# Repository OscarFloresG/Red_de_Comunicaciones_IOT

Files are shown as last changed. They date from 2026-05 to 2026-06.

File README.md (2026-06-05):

# Red de Comunicaciones IoT para - UABC

Este repositorio contiene el ecosistema de desarrollo de hardware y firmware para la implementación de una red privada de telemetría inalámbrica de largo alcance y bajo consumo, diseñada en vinculación con el Instituto de Ingeniería de la Universidad Autónoma de Baja California (UABC) para el monitoreo de consumo eléctrico en comunidades aisladas (Caso de estudio: Puertecitos, B.C.).

El sistema implementa la tecnología de radiofrecuencia LoRa en la banda libre de 915 MHz, logrando una tasa de pérdida de paquetes muy baja en entornos exteriores a distancias críticas de 300 metros, superando la atenuación por obstáculos físicos y mitigando colisiones por transmisiones concurrentes.

---

## 🛠️ Estructura del Repositorio

* `/placa_lora2`: Archivos de diseño asistido por computadora (CAD) electrónicos correspondientes a la primera etapa de la PCB adaptadora para la integración del transceptor RFM95W y el microcontrolador.
* `/PVVCSMD`: Proyecciones y diseños avanzados de la placa de circuito impreso migrada a tecnología de montaje superficial (SMD) para la optimización de espacio y reducción de costos de fabricación.
* `emisorLora.ino`: Código fuente en C++ para los nodos emisores integrados en los medidores comunitarios. Implementa la estructura de la trama personalizada y el algoritmo de desfasamiento temporal.
* `receptorCentralLora.ino`: Código fuente en C++ para el nodo base centralizador o Gateway encargado de la recepción simultánea, validación de redundancia de errores y puenteo de datos hacia servidores en la nube.

---

## 💻 Descripción de los Códigos de Firmware

### 1. Emisor (`emisorLora.ino`)
Firmware programado para ejecutarse en las unidades remotas de medición. Sus funciones principales son:
* **Estructuración de Trama Propia:** Empaqueta los datos de telemetría bajo un formato optimizado de bajo overhead: `[ID | Seq | Len | Payload | Checksum]` para agilizar el tiempo en el aire (Time-on-Air).
* **Algoritmo de Jitter Aleatorio (Anticolisiones):** Utiliza el ruido electromagnético caótico captado por un pin analógico configurado al aire como semilla para generar un desfasamiento dinámico de +/- 800 ms. Esto evita que los nodos que transmiten simultáneamente bloqueen el canal de comunicación.
* **Control de Errores:** Realiza cálculos de redundancia de datos mediante suma de verificación XOR por software antes de enviar el paquete por el transceptor.

### 2. Receptor Central (`receptorCentralLora.ino`)
Firmware dedicado al Gateway o nodo base de recolección local. Sus funciones principales son:
* **Escucha Concurrente y Modulación:** Configura el módulo de radio bajo parámetros de alta sensibilidad en la frecuencia de 915 MHz, Ancho de Banda (BW) de 125 kHz y Factor de Ensanchamiento (SF) de 7.
* **Doble Validación de Integridad:** Corrobora la exactitud de los bits recibidos mediante el análisis combinado de CRC por hardware y la verificación XOR por software, descartando tramas corruptas provocadas por interferencias del entorno.
* **Métricas de Diagnóstico:** Extrae y evalúa en tiempo real los valores de RSSI (Indicador de Fuerza de Señal Recibida) y SNR (Relación Señal-Ruido) para el diagnóstico físico del enlace.

---

## 📡 Especificaciones de Radiofrecuencia (RF)
* **Tecnología:** LoRa (Chipset Semtech SX1276 / RFM95W)
* **Frecuencia:** 915 MHz (Banda ISM libre para México)
* **Ancho de Banda (BW):** 125 kHz
* **Spreading Factor (SF):** 7
* **Potencia de Salida:** 17 dBm (50 mW)

---

## 👥 Desarrolladores
* Diego Castañeda Covarrubias
* Oscar Eduardo Flores García
* Herick Gerardo Vizcarra Macías

*Proyecto de Vinculación con Valor en Créditos (PVVC) bajo la mentoría del Dr. Saúl - Laboratorio de Energías Renovables, Instituto de Ingeniería de la UABC.*

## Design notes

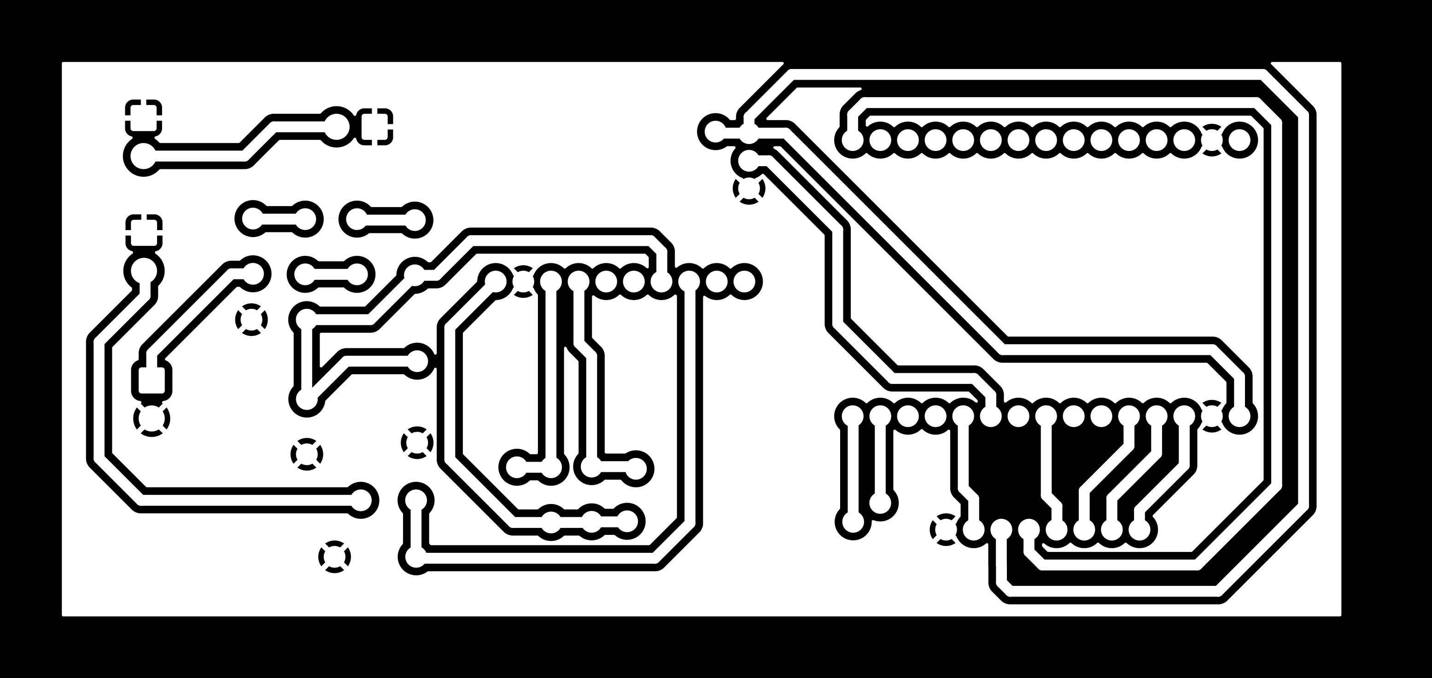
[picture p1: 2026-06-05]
placa_ceener/placa_ceener/placa_ceener-B_Cu.png

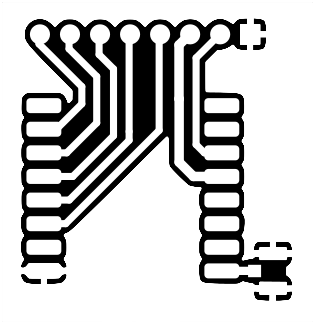
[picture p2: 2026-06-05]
placa_lora2/placa_lora2/placa_lora2-F_Cu.png

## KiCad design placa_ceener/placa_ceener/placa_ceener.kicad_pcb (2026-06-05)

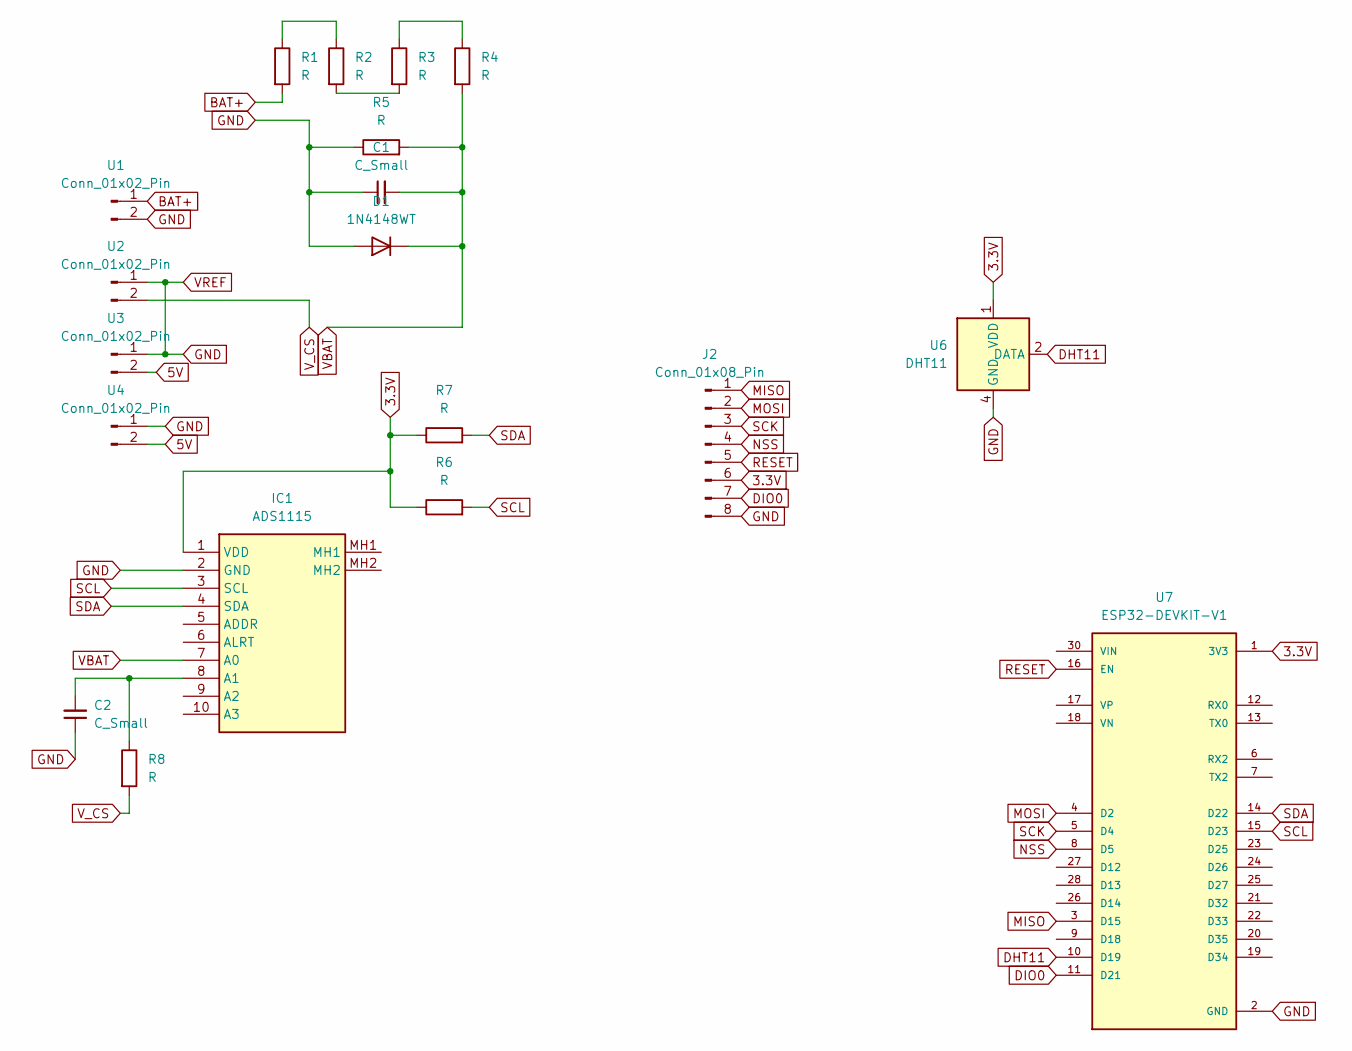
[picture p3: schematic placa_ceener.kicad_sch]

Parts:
C1, C2: C_Small; C_Axial_L3.8mm_D2.6mm_P7.50mm_Horizontal
D1: 1N4148WT; D_DO-34_SOD68_P5.08mm_Vertical_KathodeUp
IC1: ADS1115; Manufacturer_Part_Number ADS1115
J2: Conn_01x08_Pin; PinHeader_1x08_P2.54mm_Vertical
R1, R2, R3, R4, R5, R6, R7, R8: R; R_Axial_DIN0204_L3.6mm_D1.6mm_P5.08mm_Horizontal
U1, U2, U3, U4: Conn_01x02_Pin; TerminalBlock_4Ucon_1x02_P3.50mm_Horizontal
U6: DHT11; Aosong_DHT11_5.5x12.0_P2.54mm
U7: ESP32-DEVKIT-V1; MODULE_ESP32_DEVKIT_V1; PARTREV N/A

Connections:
3.3V: IC1.1 (VDD), J2.6, R6.1, R7.1, U6.1 (VDD), U7.1 (3V3)
5V: U3.2, U4.2
BAT+: R1.2, U1.1
DHT11: U6.2 (DATA), U7.10 (D19)
DIO0: J2.7, U7.11 (D21)
GND: C1.1, C2.1, D1.2 (A), IC1.2 (GND), J2.8, R5.1, U1.2, U2.1, U3.1, U4.1, U6.4 (GND), U7.2 (GND), U7.29 (GND)
MISO: J2.1, U7.3 (D15)
MOSI: J2.2, U7.4 (D2)
NSS: J2.4, U7.8 (D5)
unnamed: C2.2, IC1.8 (A1), R8.1
unnamed: R1.1, R2.1
unnamed: R2.2, R3.2
unnamed: R3.1, R4.1
RESET: J2.5, U7.16 (EN)
SCK: J2.3, U7.5 (D4)
SCL: IC1.3 (SCL), R6.2, U7.15 (D23)
SDA: IC1.4 (SDA), R7.2, U7.14 (D22)
VBAT: C1.2, D1.1 (K), IC1.7 (A0), R4.2, R5.2
V_CS: R8.2, U2.2

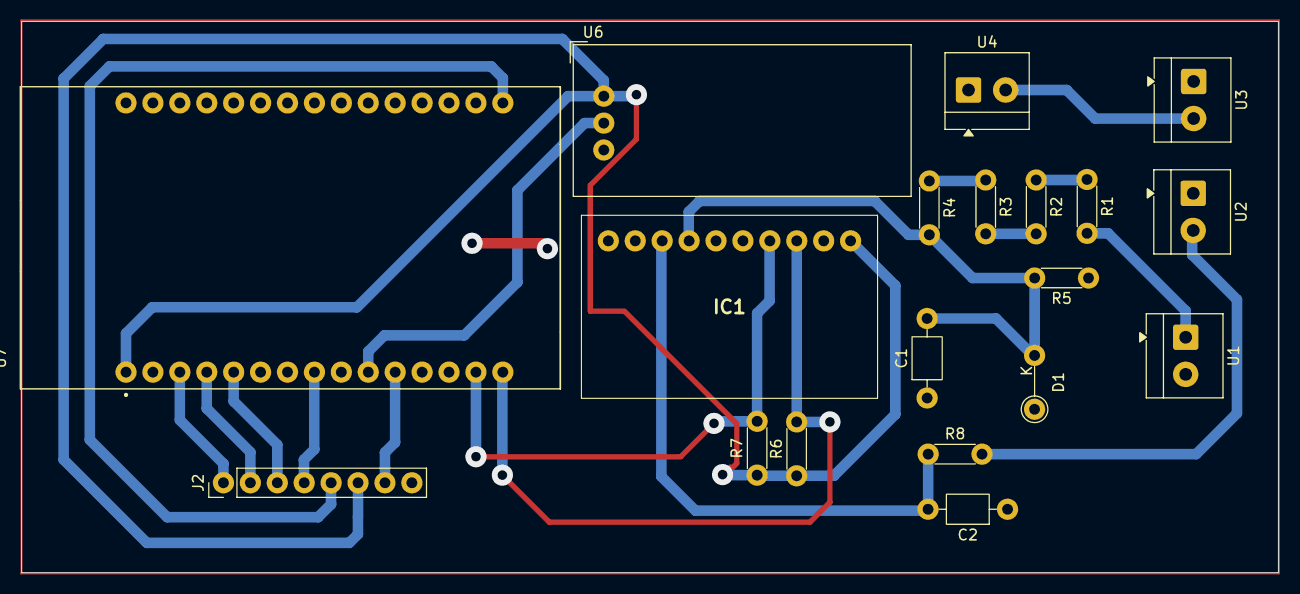
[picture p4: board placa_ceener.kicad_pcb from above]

Board: 2 copper layers, 118.6 x 52.0 mm, 19 parts (0 on the bottom side), 19 nets.

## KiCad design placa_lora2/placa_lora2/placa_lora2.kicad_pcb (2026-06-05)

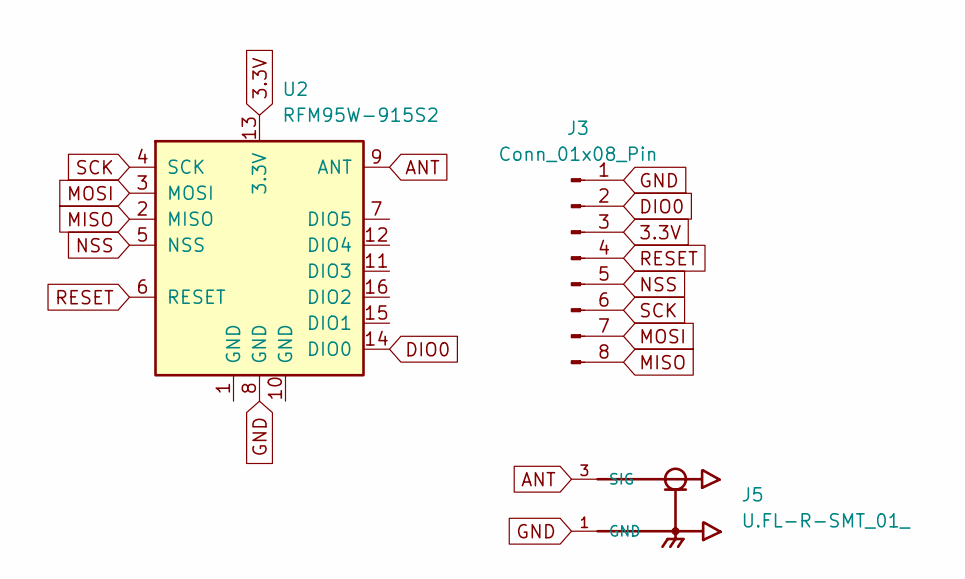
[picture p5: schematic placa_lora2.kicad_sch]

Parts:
J3: Conn_01x08_Pin; PinHeader_1x08_P2.54mm_Vertical
J5: U.FL-R-SMT_01_; HRS_U.FL-R-SMT_01_
U2: RFM95W-915S2; HOPERF_RFM9XW_SMD

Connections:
3.3V: J3.3, U2.13 (3.3V)
ANT: J5.3 (SIG), U2.9 (ANT)
DIO0: J3.2, U2.14 (DIO0)
GND: J3.1, J5.1 (GND), J5.2 (GND), U2.8 (GND)
MISO: J3.8, U2.2 (MISO)
MOSI: J3.7, U2.3 (MOSI)
NSS: J3.5, U2.5 (NSS)
RESET: J3.4, U2.6 (RESET)
SCK: J3.6, U2.4 (SCK)

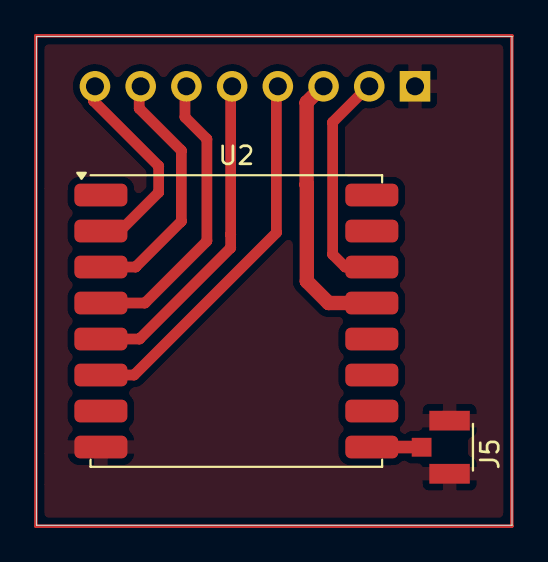
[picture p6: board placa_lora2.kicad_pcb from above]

Board: 2 copper layers, 26.4 x 27.2 mm, 3 parts (1 on the bottom side), 9 nets.

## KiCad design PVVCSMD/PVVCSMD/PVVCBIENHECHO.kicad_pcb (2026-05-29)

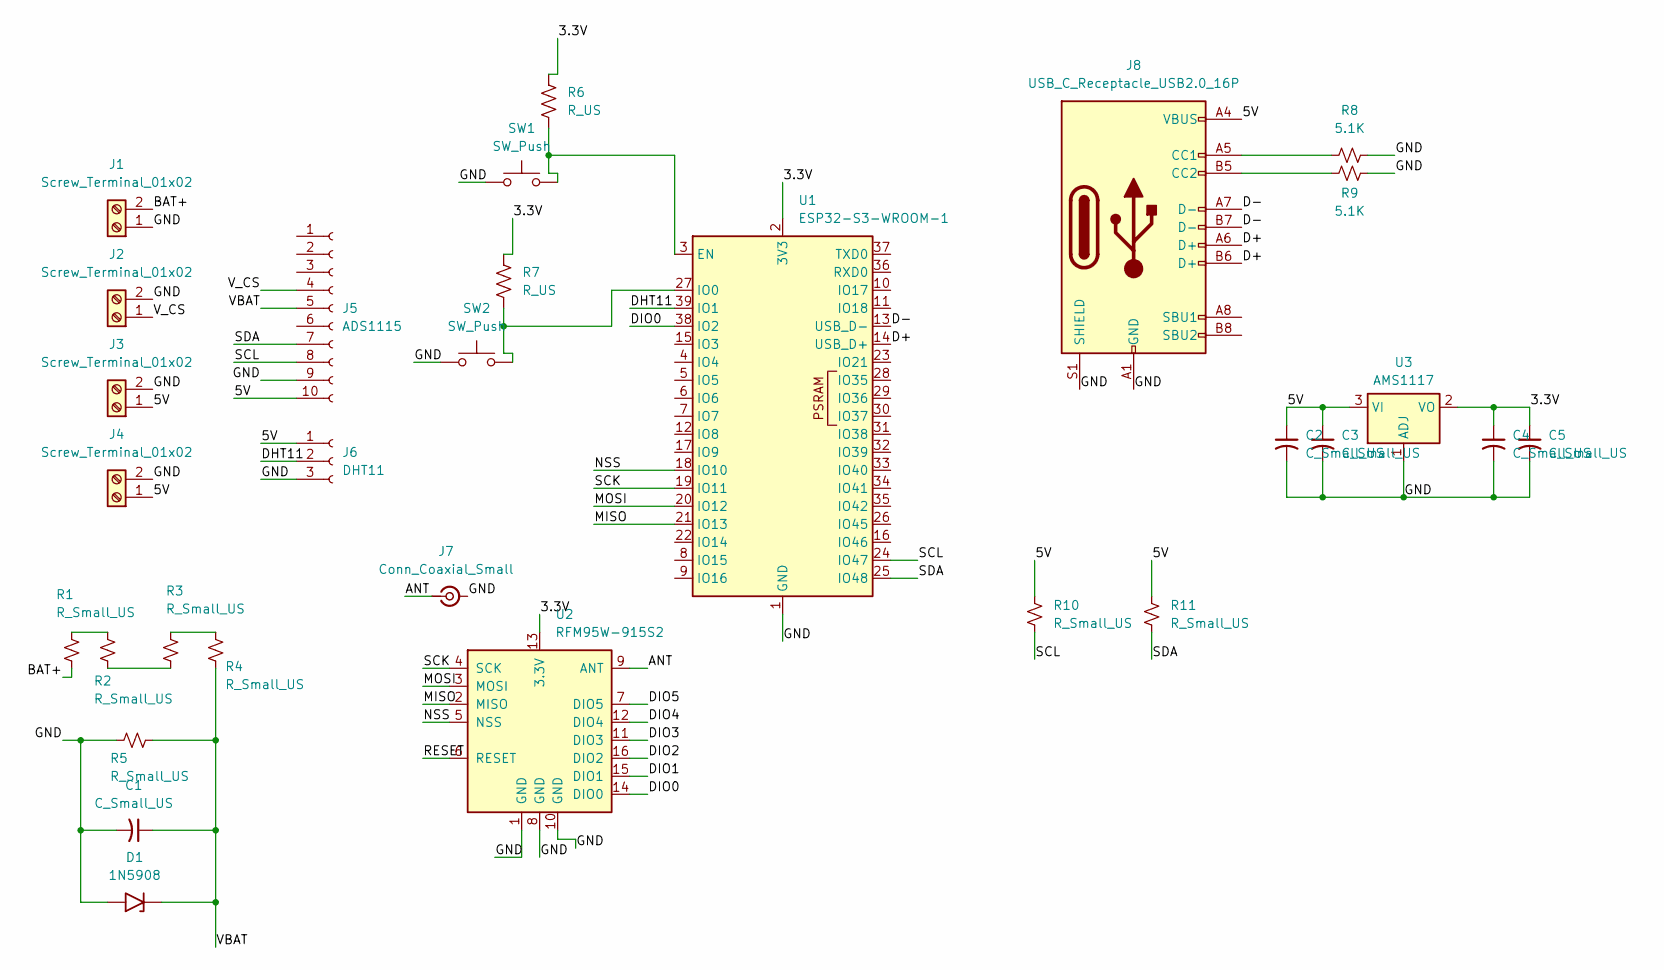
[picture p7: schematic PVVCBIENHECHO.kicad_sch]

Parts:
C1, C2, C3, C4, C5: C_Small_US; C_1206_3216Metric
D1: 1N5908; D_1206_3216Metric
J1, J2, J3, J4: Screw_Terminal_01x02; TerminalBlock_Xinya_XY308-2.54-2P_1x02_P2.54mm_Horizontal
J5: ADS1115; PinSocket_1x10_P2.54mm_Vertical
J6: DHT11; PinSocket_1x03_P2.54mm_Vertical
J7: Conn_Coaxial_Small; U.FL_Hirose_U.FL-R-SMT-1_Vertical
J8: USB_C_Receptacle_USB2.0_16P; USB_C_Receptacle_HRO_TYPE-C-31-M-12
R1, R2, R3, R4, R5, R10, R11: R_Small_US; R_1206_3216Metric
R6, R7: R_US; R_1206_3216Metric
R8, R9: 5.1K; R_1206_3216Metric
SW1, SW2: SW_Push; SW_PUSH_6mm_H8mm
U1: ESP32-S3-WROOM-1
U2: RFM95W-915S2; HOPERF_RFM9XW_SMD
U3: AMS1117; SOT-223-3_TabPin2

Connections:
/3.3V: C4.1, C5.1, R6.1, R7.1, U1.2 (3V3), U2.13 (3.3V), U3.2 (VO)
/5V: C2.1, C3.1, J3.1, J4.1, J5.10, J6.1, J8.A4 (VBUS), J8.A9 (VBUS), J8.B4 (VBUS), J8.B9 (VBUS), R10.1, R11.1, U3.3 (VI)
/ANT: J7.1 (In), U2.9 (ANT)
/BAT+: J1.2, R1.2
/D+: J8.A6 (D+), J8.B6 (D+), U1.14 (USB_D+)
/D-: J8.A7 (D-), J8.B7 (D-), U1.13 (USB_D-)
/DHT11: J6.2, U1.39 (IO1)
/DIO0: U1.38 (IO2), U2.14 (DIO0)
/DIO1: U2.15 (DIO1)
/DIO2: U2.16 (DIO2)
/DIO3: U2.11 (DIO3)
/DIO4: U2.12 (DIO4)
/DIO5: U2.7 (DIO5)
/GND: C1.2, C2.2, C3.2, C4.2, C5.2, D1.2 (A2), J1.1, J2.2, J3.2, J4.2, J5.9, J6.3, J7.2 (Ext), J8.A1 (GND), J8.A12 (GND), J8.B1 (GND), J8.B12 (GND), J8.S1 (SHIELD), R5.2, R8.2, R9.2, SW1.1, SW2.1, U1.1 (GND), U1.40 (GND), U1.41 (GND), U2.1 (GND), U2.8 (GND), U2.10 (GND), U3.1 (ADJ)
/MISO: U1.21 (IO13), U2.2 (MISO)
/MOSI: U1.20 (IO12), U2.3 (MOSI)
/NSS: U1.18 (IO10), U2.5 (NSS)
/RESET: U2.6 (RESET)
/SCK: U1.19 (IO11), U2.4 (SCK)
/SCL: J5.8, R10.2, U1.24 (IO47)
/SDA: J5.7, R11.2, U1.25 (IO48)
/VBAT: C1.1, D1.1 (A1), J5.5, R4.2, R5.1
/V_CS: J2.1, J5.4
unnamed: J8.A5 (CC1), R8.1
unnamed: J8.B5 (CC2), R9.1
unnamed: R1.1, R2.1
unnamed: R2.2, R3.2
unnamed: R3.1, R4.1
unnamed: R6.2, SW1.2, U1.3 (EN)
unnamed: R7.2, SW2.2, U1.27 (IO0)

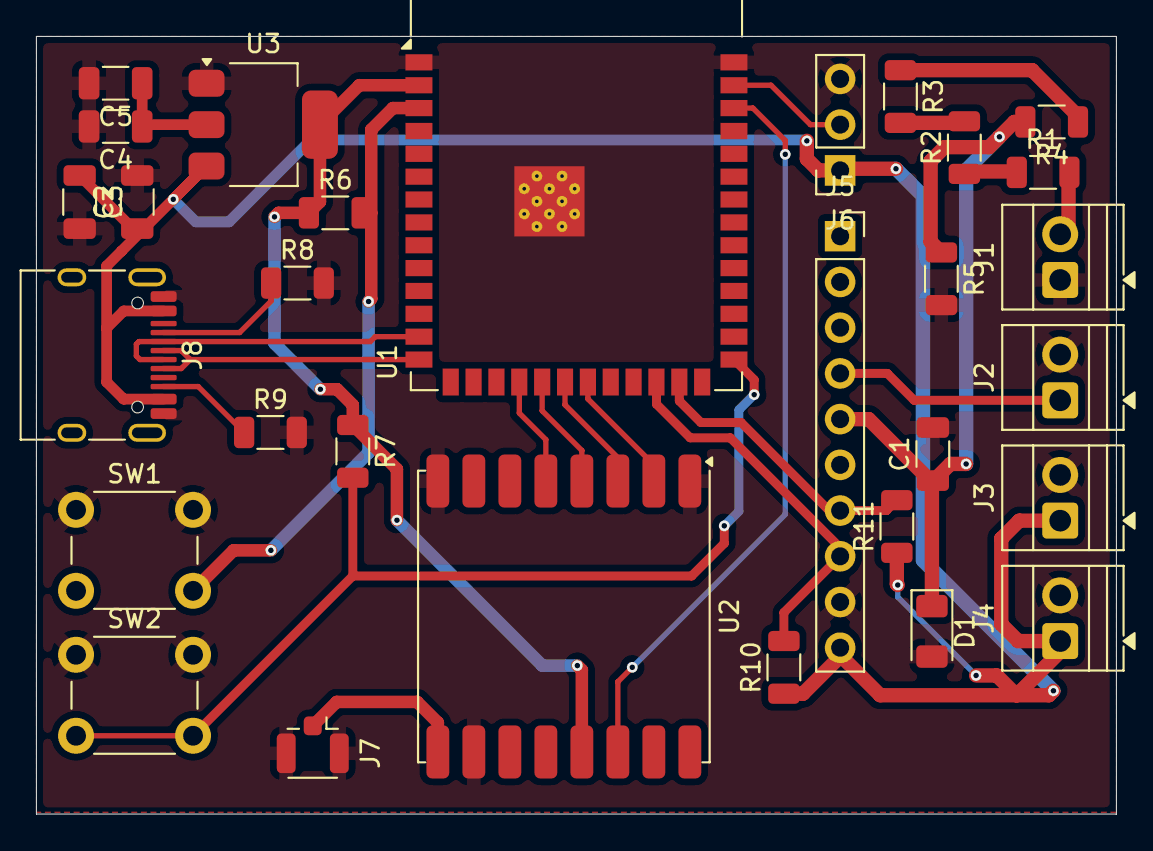
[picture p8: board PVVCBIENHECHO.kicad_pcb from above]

Board: 2 copper layers, 60.0 x 43.2 mm, 30 parts (0 on the bottom side), 24 nets.

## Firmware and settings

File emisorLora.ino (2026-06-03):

/*
 * =====================================================
 * NODO CLIENTE - LoRa Transmitter
 * ESP32 + LoRa SX1276/SX1278
 * =====================================================
 * *** ÚNICO CAMBIO ENTRE CLIENTES: NODE_ID (línea 30) ***
 * Cliente 1 → NODE_ID 0xA1
 * Cliente 2 → NODE_ID 0xA2
 * Cliente 3 → NODE_ID 0xA3
 * (y así sucesivamente...)
 *
 * Todos los demás parámetros deben ser IDÉNTICOS al base.
 * =====================================================
 */

#include <SPI.h>
#include <LoRa.h>

// ── Pines (TTGO LoRa32 / ajustar si es necesario) ──
#define LORA_SCK   4
#define LORA_MISO  15
#define LORA_MOSI  2
#define LORA_SS    5
#define LORA_RST   14
#define LORA_DIO0  21

// ── ★★ CAMBIA ESTO EN CADA ESP32 ★★ ──────────────
#define NODE_ID  0xA2          // 0xA1, 0xA2, 0xA3, 0xA4...
// ──────────────────────────────────────────────────

// ── Parámetros de radio (IDÉNTICOS en todos los nodos) ──
#define LORA_FREQ       915E6
#define LORA_BW         125E3
#define LORA_SF         9
#define LORA_CR         5
#define LORA_TX_POWER   17
#define LORA_PREAMBLE   8
#define LORA_SYNC_WORD  0xF3

// ── ID del nodo destino (base) ──
#define BASE_ID    0x00

// ── Intervalo base de transmisión (ms) y rango de Jitter ──
#define TX_INTERVAL_MS   5000    // Tiempo base: 5 segundos
#define JITTER_RANGE_MS  800     // Desfase de +/- 800ms (Total entre 4.2s y 5.8s)

// ── Estructura del paquete ──
#define PKT_SRC_ID      0
#define PKT_SEQ         1
#define PKT_LEN         2
#define PKT_PAYLOAD     3
#define PKT_HEADER_SIZE 3
#define PKT_MAX_PAYLOAD 50

// ── Contador de secuencia y tiempos ──
uint8_t seq_counter = 0;
uint32_t last_tx_ms = 0;
uint32_t current_interval = TX_INTERVAL_MS; // Intervalo dinámico actual

// ──────────────────────────────────────────────────
void setup() {
  Serial.begin(115200);
  delay(500);
  Serial.println("\n=== NODO CLIENTE LoRa ===");
  Serial.printf("  ID: 0x%02X  |  Destino: 0x%02X\n", NODE_ID, BASE_ID);

  // Inicializar semilla aleatoria usando ruido de un pin analógico sin conectar (ej. GPIO 34)
  // Esto evita que todos los emisores generen el mismo patrón al encenderse juntos.
  randomSeed(analogRead(34) + NODE_ID);

  SPI.begin(LORA_SCK, LORA_MISO, LORA_MOSI, LORA_SS);
  LoRa.setPins(LORA_SS, LORA_RST, LORA_DIO0);

  if (!LoRa.begin(LORA_FREQ)) {
    Serial.println("[ERROR] LoRa no inicializado. Revisa conexiones.");
    while (true) { delay(1000); }
  }

  LoRa.setSignalBandwidth(LORA_BW);
  LoRa.setSpreadingFactor(LORA_SF);
  LoRa.setCodingRate4(LORA_CR);
  LoRa.setTxPower(LORA_TX_POWER);
  LoRa.setPreambleLength(LORA_PREAMBLE);
  LoRa.setSyncWord(LORA_SYNC_WORD);
  LoRa.enableCrc();

  // Calcular el primer intervalo aleatorio para romper la simetría inicial
  current_interval = TX_INTERVAL_MS + random(-JITTER_RANGE_MS, JITTER_RANGE_MS);

  Serial.println("[OK] LoRa listo. Transmitiendo...\n");
}

// ──────────────────────────────────────────────────
void loop() {
  uint32_t now = millis();
  
  // Comparamos contra el intervalo dinámico en vez del estático
  if (now - last_tx_ms >= current_interval) {
    last_tx_ms = now;

    // Calcular el intervalo para el SIGUIENTE paquete
    current_interval = TX_INTERVAL_MS + random(-JITTER_RANGE_MS, JITTER_RANGE_MS);

    // ── Arma tu payload aquí ──────────────────────
    float temp   = 22.5 + (random(-30, 30) / 10.0);
    uint32_t uptime_s = now / 1000;

    char payload[PKT_MAX_PAYLOAD];
    int payload_len = snprintf(payload, sizeof(payload),
                               "T:%.1f C  up:%lus", temp, uptime_s);
    if (payload_len < 0 || payload_len >= PKT_MAX_PAYLOAD) {
      payload_len = PKT_MAX_PAYLOAD - 1;
    }
    // ─────────────────────────────────────────────

    send_packet((uint8_t*)payload, (uint8_t)payload_len);
    
    Serial.printf("[INFO] Próximo envío en: %.2f segundos.\n", current_interval / 1000.0);
  }
}

// ──────────────────────────────────────────────────
void send_packet(uint8_t* data, uint8_t data_len) {
  // Construir buffer: [ src_id | seq | len | payload | checksum ]
  uint8_t buf[PKT_HEADER_SIZE + PKT_MAX_PAYLOAD + 1];
  buf[PKT_SRC_ID] = NODE_ID;
  buf[PKT_SEQ]    = seq_counter++;
  buf[PKT_LEN]    = data_len;
  memcpy(&buf[PKT_PAYLOAD], data, data_len);

  // Checksum: XOR de todos los bytes anteriores
  uint8_t chk = 0;
  int total = PKT_HEADER_SIZE + data_len;
  for (int i = 0; i < total; i++) chk ^= buf[i];
  buf[total] = chk;

  // Transmitir
  LoRa.beginPacket();
  LoRa.write(buf, total + 1);
  bool ok = LoRa.endPacket();

  Serial.printf("[TX] ID:0x%02X  Seq:%d  Len:%d  OK:%s  Data: %.*s\n",
                NODE_ID, buf[PKT_SEQ], data_len,
                ok ? "si" : "no", data_len, (char*)data);
}

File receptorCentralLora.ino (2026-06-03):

/*
 * =====================================================
 *  NODO BASE - LoRa Receiver
 *  ESP32 + LoRa SX1276/SX1278 (TTGO LoRa32 / Heltec)
 * =====================================================
 *  Librería: LoRa by Sandeep Mistry (Arduino Library Manager)
 *  pip: "LoRa" de sandeepmistry
 *
 *  Pinout para TTGO LoRa32 v2.1 (ajusta si usas otra placa):

*    SCK  → 5    MISO → 19   MOSI → 27
 *    SS   → 18   RST  → 14   DIO0 → 26
 * =====================================================

*/

#include <SPI.h>
#include <LoRa.h>

// ── Pines (TTGO LoRa32 / ajustar si es necesario) ──
#define LORA_SCK 4
#define LORA_MISO 15
#define LORA_MOSI 2
#define LORA_SS 5
#define LORA_RST 14
#define LORA_DIO0 21

// ── Parámetros de radio (deben coincidir en TODOS los nodos) ──

define LORA_FREQ 915E6  // 915 MHz (USA/MX). Usa 868E6 en Europa.

define LORA_BW 125E3  // Bandwidth 125 kHz
#define LORA_SF 9  // Spreading Factor 9  (rango/velocidad)
#define LORA_CR 5  // Coding Rate 4/5
#define LORA_TX_POWER 17  // dBm (máx 20, legal MX ~14-17)
#define LORA_PREAMBLE 8  // símbolos de preámbulo
#define LORA_SYNC_WORD 0xF3  // "Red privada" — cambia para aislarla

// ── ID de este nodo ──
#define NODE_ID 0x00  // Base = 0x00

// ── Estructura del paquete ──
// [ 1B src_id ][ 1B seq_num ][ 1B payload_len ][ N bytes payload ][ 1B checksum ]
#define PKT_SRC_ID 0
#define PKT_SEQ 1
#define PKT_LEN 2
#define PKT_PAYLOAD 3
#define PKT_HEADER_SIZE 3
#define PKT_MAX_PAYLOAD 50

// ── Tabla de clientes conocidos ──
#define MAX_CLIENTS 16
struct ClientInfo {
  uint8_t id;
  uint32_t last_seen_ms;
  uint16_t packets_rx;
  int16_t last_rssi;
  float last_snr;
;
ClientInfo clients[MAX_CLIENTS];
uint8_t client_count = 0;

// ──────────────────────────────────────────────────
void setup() {
  Serial.begin(115200);
  delay(500);
  Serial.println("\n=== NODO BASE LoRa ===");
  Serial.printf("  ID: 0x%02X  |  Freq: %.0f MHz\n", NODE_ID, LORA_FREQ / 1e6);


 SPI.begin(LORA_SCK, LORA_MISO, LORA_MOSI, LORA_SS);
  LoRa.setPins(LORA_SS, LORA_RST, LORA_DIO0);

  if (!LoRa.begin(LORA_FREQ)) {
    Serial.println("[ERROR] LoRa no inicializado. Revisa conexiones.");
    while (true) { delay(1000); }
 }

  LoRa.setSignalBandwidth(LORA_BW);
  LoRa.setSpreadingFactor(LORA_SF);
  LoRa.setCodingRate4(LORA_CR);
  LoRa.setTxPower(LORA_TX_POWER);
  LoRa.setPreambleLength(LORA_PREAMBLE);
  LoRa.setSyncWord(LORA_SYNC_WORD);
  LoRa.enableCrc();

  Serial.println("[OK] LoRa listo. Escuchando...\n");


// ──────────────────────────────────────────────────
void loop() {
  int pkt_size = LoRa.parsePacket();
  if (pkt_size > 0) {
    handle_incoming(pkt_size);
  }

  // truco extra: Si el chip se queda colgado por ruido,
  // esto asegura que siga en modo recepción continua.
  // (No afecta si ya está escuchando)
  LoRa.receive();
}

// ──────────────────────────────────────────────────

// ──────────────────────────────────────────────────
void handle_incoming(int pkt_size) {
  // Asegurarnos de no desbordar nuestro buffer local si viene basura gigante por colisión
  uint8_t buf[PKT_MAX_PAYLOAD + PKT_HEADER_SIZE + 1];
  int len = 0;

  // Leer los datos limitando estrictamente al tamaño del buffer
  while (LoRa.available() && len < (int)sizeof(buf)) {
    buf[len++] = LoRa.read();
  }

  // ¡CRUCIAL!: Si quedaron bytes en el buffer del chip por culpa de la interferencia,
  // los limpiamos por completo para que no afecten al siguiente paquete.
  while (LoRa.available()) {
    LoRa.read();
  }

  // Ahora sí, validamos longitud mínima
  if (len < PKT_HEADER_SIZE + 1) {
    Serial.println("[WARN] Paquete corrupto o incompleto por colisión. Descartado.");
    LoRa.receive();  // Forzar modo escucha antes de salir
    return;
  }

  // Verificar checksum
  uint8_t chk = 0;
  for (int i = 0; i < len - 1; i++) chk ^= buf[i];
  if (chk != buf[len - 1]) {
    Serial.printf("[WARN] Checksum inválido (calculado 0x%02X, recibido 0x%02X) - Posible interferencia.\n",
                  chk, buf[len - 1]);
    LoRa.receive();  // Forzar modo escucha antes de salir
    return;
  }

  uint8_t src_id = buf[PKT_SRC_ID];
  uint8_t seq_num = buf[PKT_SEQ];
  uint8_t payload_len = buf[PKT_LEN];
  int16_t rssi = LoRa.packetRssi();
  float snr = LoRa.packetSnr();

  // Registrar / actualizar cliente
  update_client(src_id, rssi, snr);

  // Extraer payload como string
  char payload[PKT_MAX_PAYLOAD + 1] = { 0 };
  if (payload_len > PKT_MAX_PAYLOAD) payload_len = PKT_MAX_PAYLOAD;
  memcpy(payload, &buf[PKT_PAYLOAD], payload_len);
  payload[payload_len] = '\0';

  // Imprimir en formato legible
  Serial.println("┌─────────────────────────────────────");
  Serial.printf("│ De:    0x%02X   Seq: %d\n", src_id, seq_num);
  Serial.printf("│ RSSI:  %d dBm   SNR: %.1f dB\n", rssi, snr);
  Serial.printf("│ Data:  %s\n", payload);
  Serial.println("└─────────────────────────────────────");

  // Forzar al radio a regresar al modo de escucha activa
  LoRa.receive();
}



// ──────────────────────────────────────────────────
void update_client(uint8_t id, int16_t rssi, float snr) {
  for (int i = 0; i < client_count; i++) {
    if (clients[i].id == id) {
      clients[i].last_seen_ms = millis();
      clients[i].packets_rx++;
      clients[i].last_rssi = rssi;
      clients[i].last_snr = snr;
      return;
   }
 }
  // Cliente nuevo
  if (client_count < MAX_CLIENTS) {
    clients[client_count++] = { id, millis(), 1, rssi, snr };
    Serial.printf("[INFO] Nuevo cliente registrado: 0x%02X (total: %d)\n", id, client_count);
 }

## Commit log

2026-05-29 Proyecto KiCad con diseño de componentes SMD
    [PVVCBIENHECHO.kicad_pcb]
2026-05-29 Diseño de Placa con los componentes SMD
    [PVVCBIENHECHO.kicad_pcb, PVVCBIENHECHO.kicad_sch]
2026-06-03 Codigos apra comunicacion lora
    Archivos .ino con codigos para lora emisor y receptor.
2026-06-05 Diseño PCB del módulo LoRa
    [placa_lora2.kicad_pcb, placa_lora2.kicad_sch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]
2026-06-05 Diseño de su circuito con el módulo adaptador.
    [placa_ceener.kicad_pcb, placa_ceener.kicad_sch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]
